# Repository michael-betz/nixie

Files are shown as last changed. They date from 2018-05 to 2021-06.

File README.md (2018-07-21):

# nixie
My exercise in OpenScad.
a HP 5245L frequency counter had to die for this ...

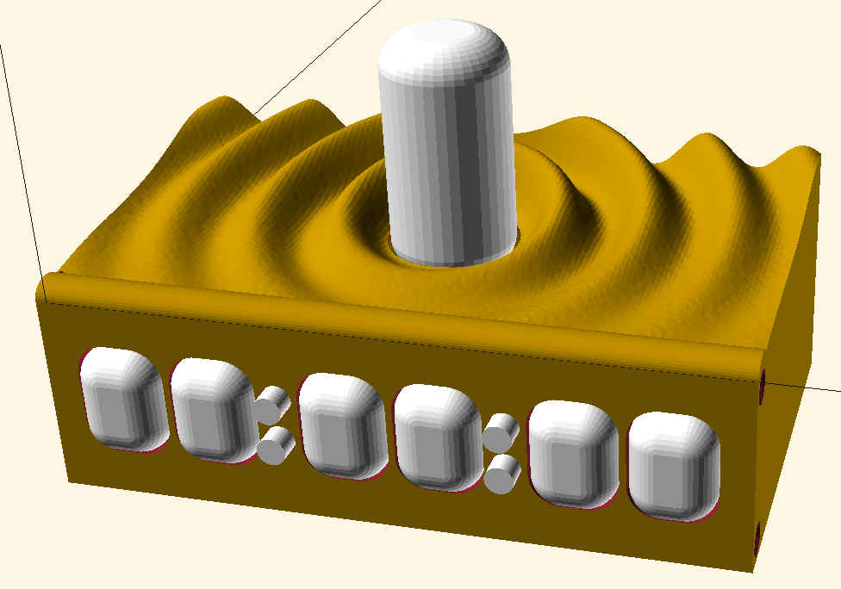
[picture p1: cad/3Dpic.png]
Nixie render

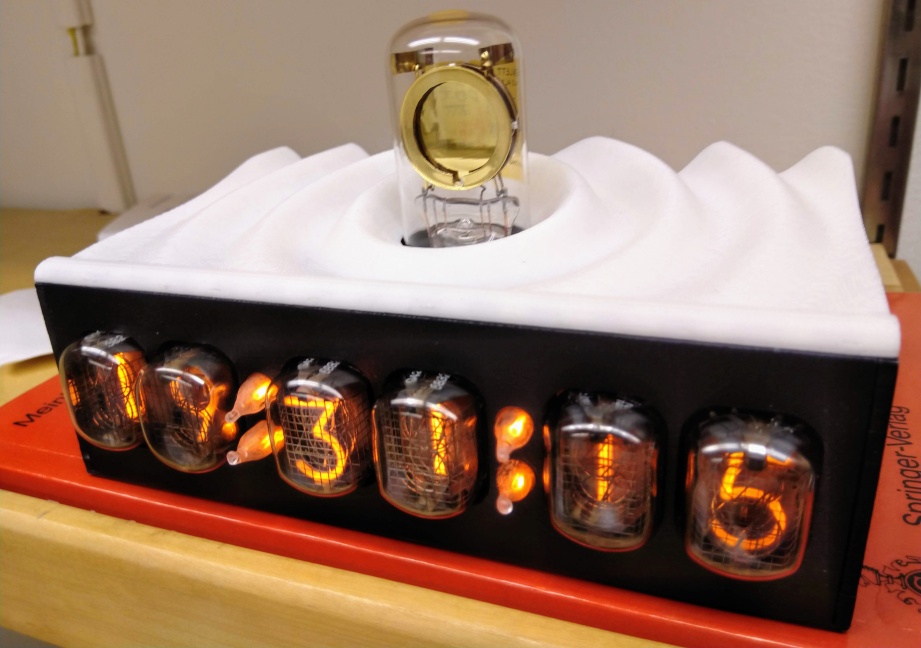
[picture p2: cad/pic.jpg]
Nixie photo


# Lessons learned the hard way
Murphy was strong on this one ...

  * Nixie pins are fragile and don't like too tight sockets. RIP 2 tubes ...
  * The HV5530 in a PQFP package has a different pinout than the one in a PLCC package. Fixed it with tons of botch wire :weary:
  * Didn't notice that the nixie tube datasheet shows the pinout from the bottom :unamused:. Fixed it with a lot more botch wire
  * Feel free to re-do the layout in kicad ...
  * Magnet wire insulation didn't hold up to 180 V. Killed 2 x ESP32 that way. Fixed it with conformal coating
  * Didn't keep conformal coating away from push buttons, it disabled them
  * Hole pattern between PCB and 3D print was off by ~ 3 mm due to a typo in the 3D model. Fixed it by bending the 3D printed part with a hot air gun
  * Had to cut some of the 3D printed stand-offs and the ESP32 PCB antenna to make it all fit

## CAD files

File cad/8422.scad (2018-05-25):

module pin() {
  translate([11.1/2, 0,        0]) cylinder(h=6, r=0.5);
  translate([11.1/2, 4.3,      0]) cylinder(h=6, r=0.5);
  translate([0,      17.1/2,   0]) cylinder(h=6, r=0.5);
  translate([sin(26)*17.1/2, cos(26)*17.1/2, 0]) cylinder(h=6, r=0.5);
}

module nixie8422(){
  smoothRad = 7;
  union(){
    minkowski(){
      cube(size=[18.85-smoothRad*2, 25.1-smoothRad*2, 20-smoothRad*2], center=true);
      sphere(r=smoothRad);
    }
    translate([0,0,-15]) union(){
      pin();
      mirror([0,1,0]) pin();
      mirror([1,0,0]) pin();
      mirror([0,1,0]) mirror([1,0,0]) pin();
    }
  }
}

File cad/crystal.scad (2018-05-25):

module crystal() {
  smoothRad = 8;
  minkowski(){
    cylinder(h=55.8-smoothRad*2, r=28.5/2-smoothRad, center=true);
    sphere(r=smoothRad);
  }
}

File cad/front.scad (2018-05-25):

// the complete frontpanel
module frontPanel(){
  difference(){
    translate([150/2,fpThickness/2,-45/2]) rotate([90,0,0]){
      difference(){
        cube(size=[150,45,fpThickness], center=true);
        nixies(1.06);
      }
      // PCB standoffs
      translate([0, 0, -pcbDist+0.5]) standOffSquare(138,33,2.7,pcbDist);
      // Teeth at the top
      translate([-150/2,45/2,2]) teeth(teethShrink, 140);
    }
    // bumper slots
    translate([0,21,0]) rotate([90,0,0]) bumpers(2.8, 20);
    // screw holes on the sides
    translate([ -0.1,fpThickness/2,   -4]) rotate([0,90,0]) cylinder(h=14, r=3.5/2);
    translate([ -0.1,fpThickness/2,-45+4]) rotate([0,90,0]) cylinder(h=14, r=3.5/2);
    translate([136.1,fpThickness/2,   -4]) rotate([0,90,0]) cylinder(h=14, r=3.5/2);
    translate([136.1,fpThickness/2,-45+4]) rotate([0,90,0]) cylinder(h=14, r=3.5/2);
  }
}

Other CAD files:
cad/helpers.scad
cad/lower.scad
cad/main.scad
cad/top.scad

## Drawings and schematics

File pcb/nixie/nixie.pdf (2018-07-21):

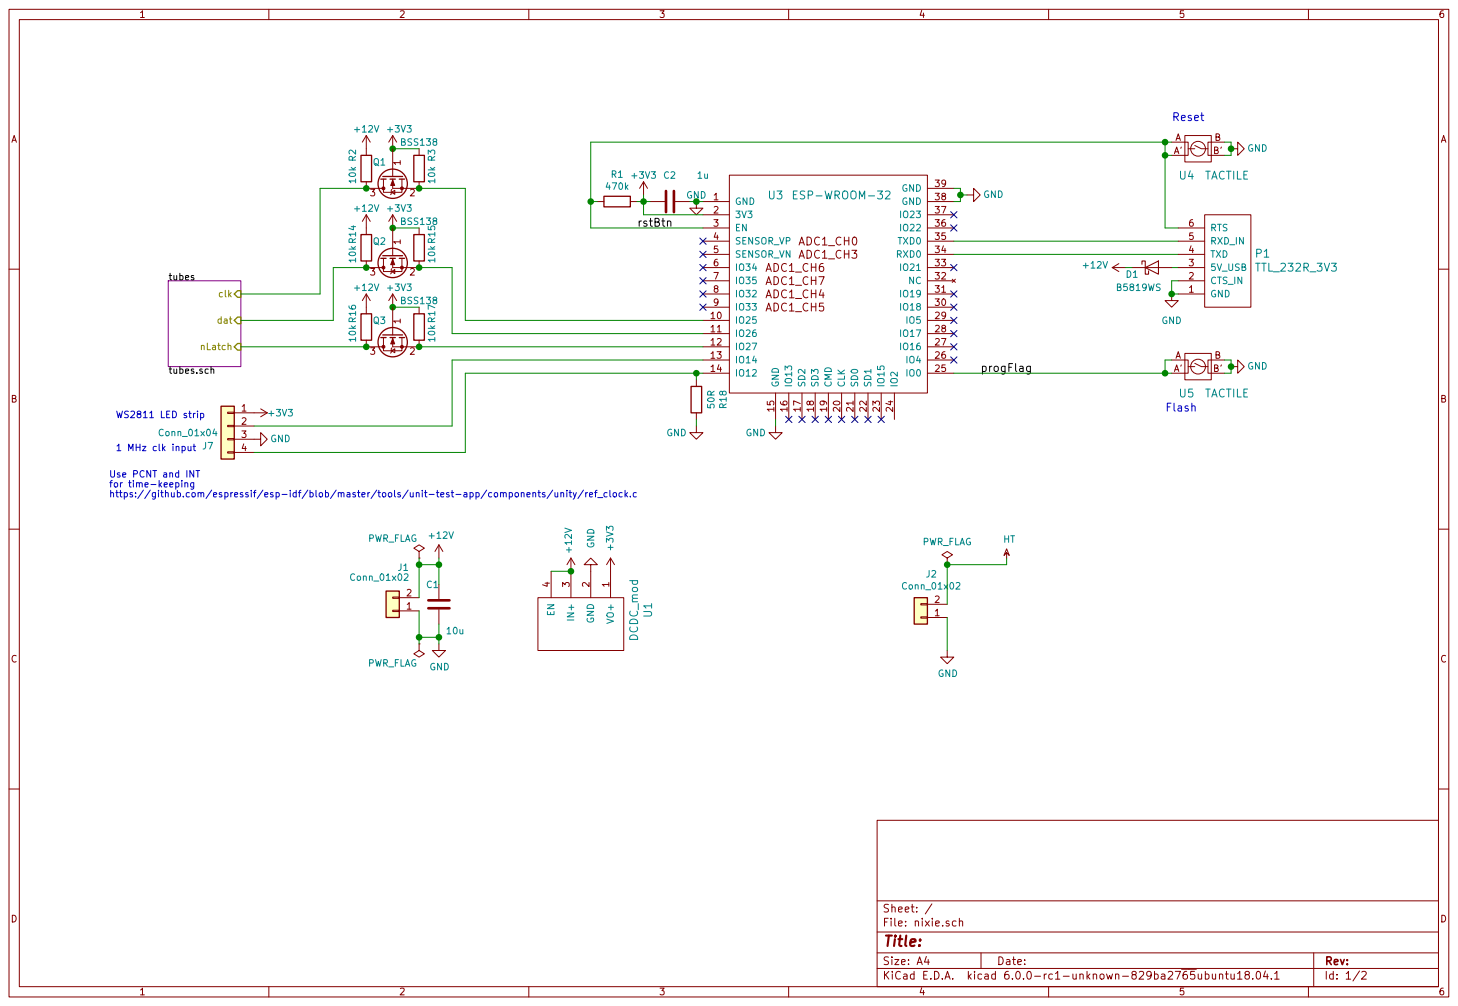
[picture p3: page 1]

1 MHz clk input Use PCNT and INT

Id: 1/2 Title: File: nixie.sch Sheet: /

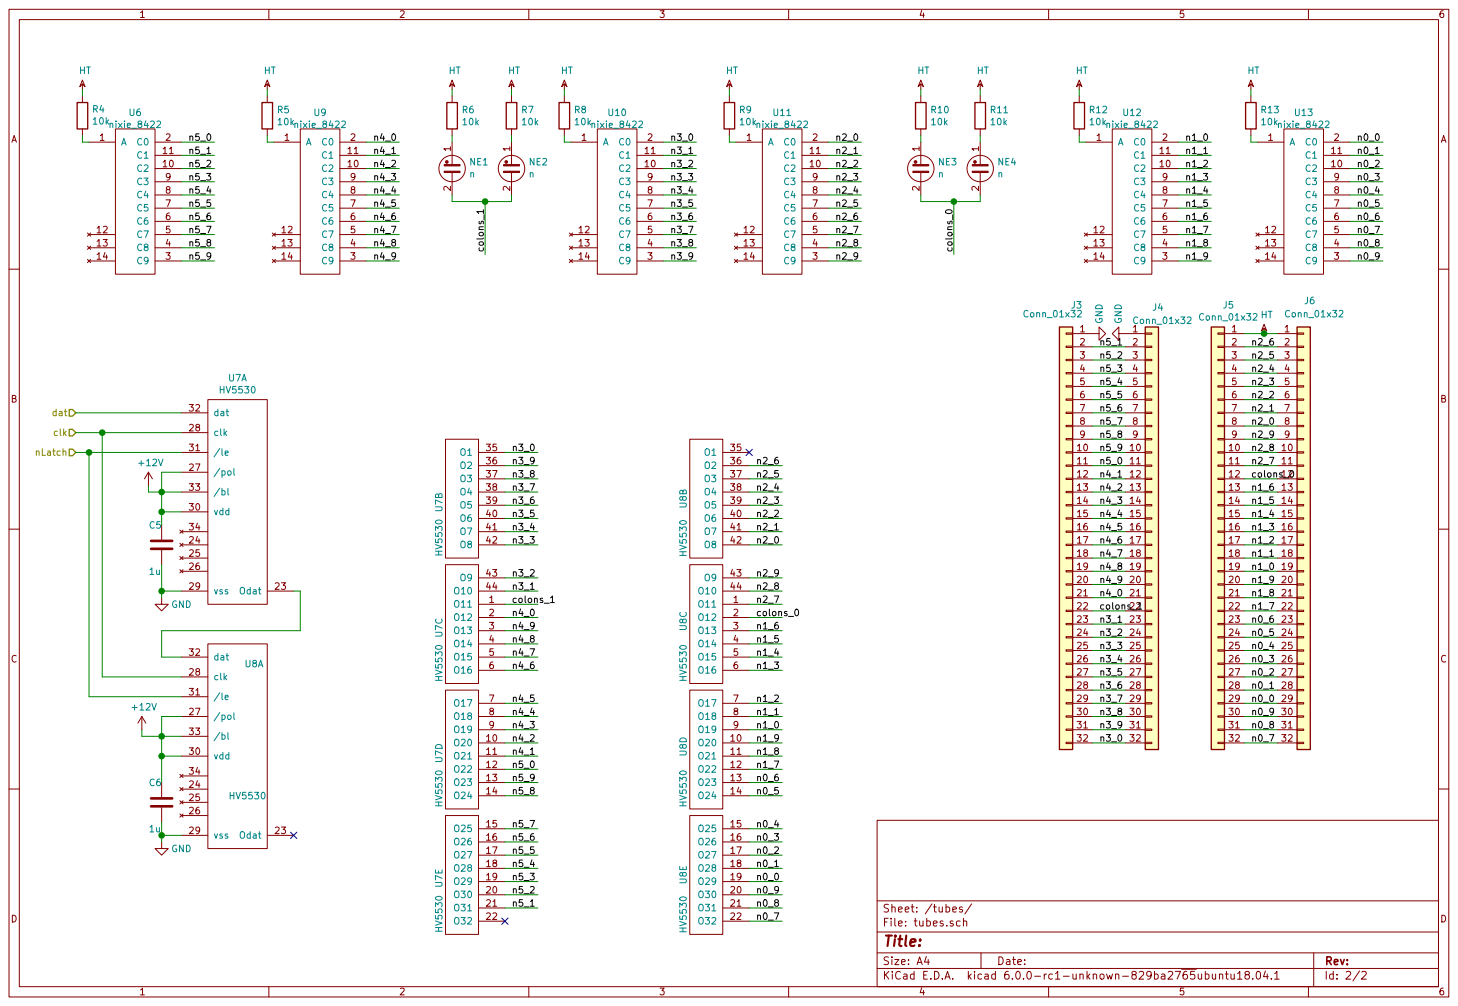
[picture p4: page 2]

Id: 2/2 Title: File: tubes.sch Sheet: /tubes/

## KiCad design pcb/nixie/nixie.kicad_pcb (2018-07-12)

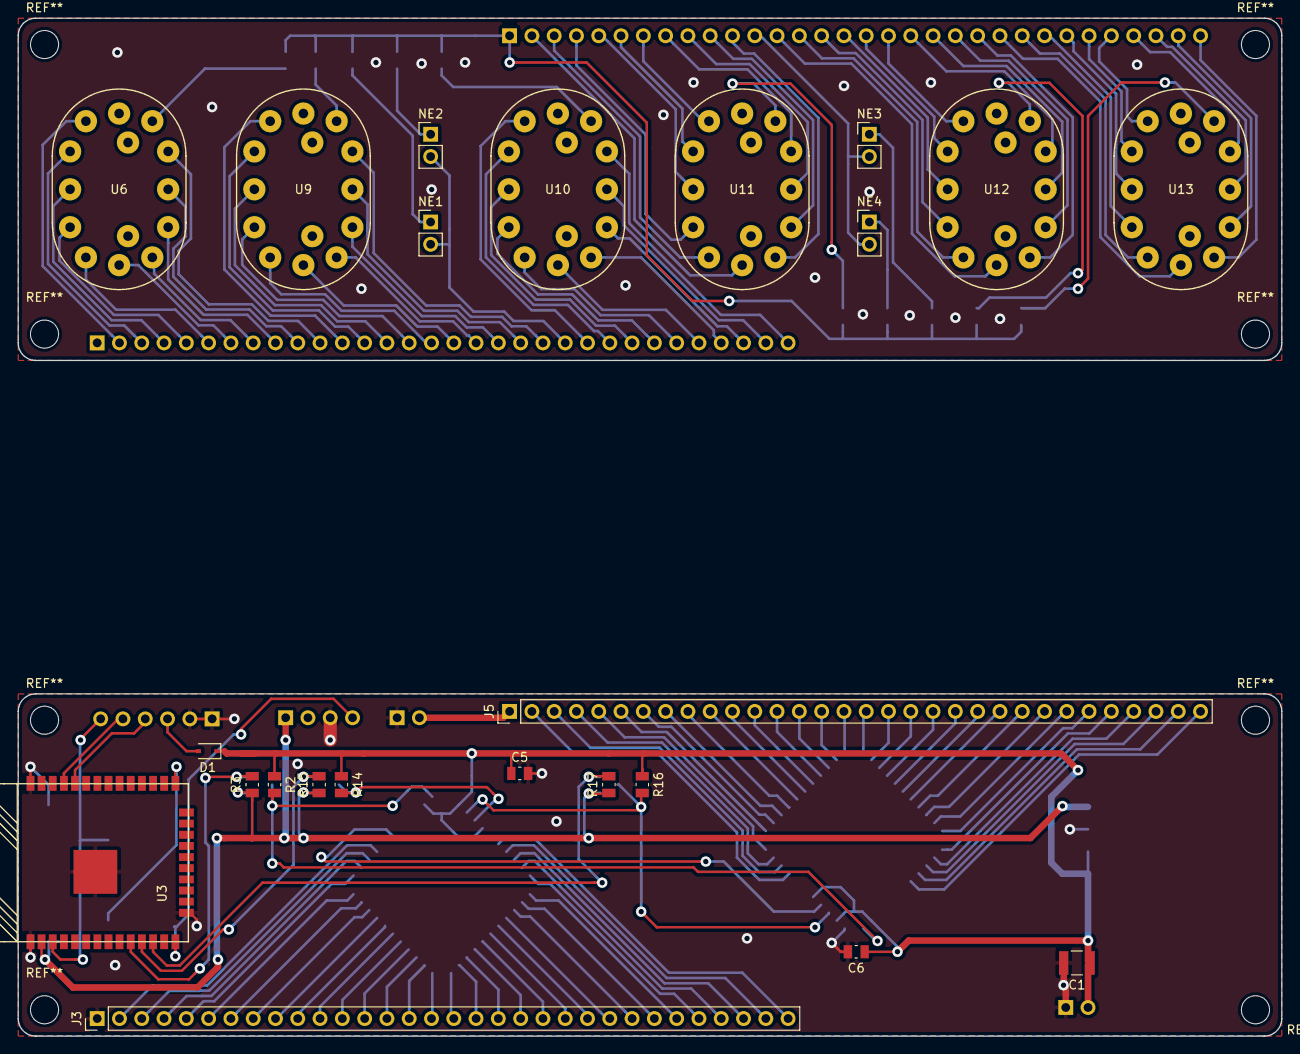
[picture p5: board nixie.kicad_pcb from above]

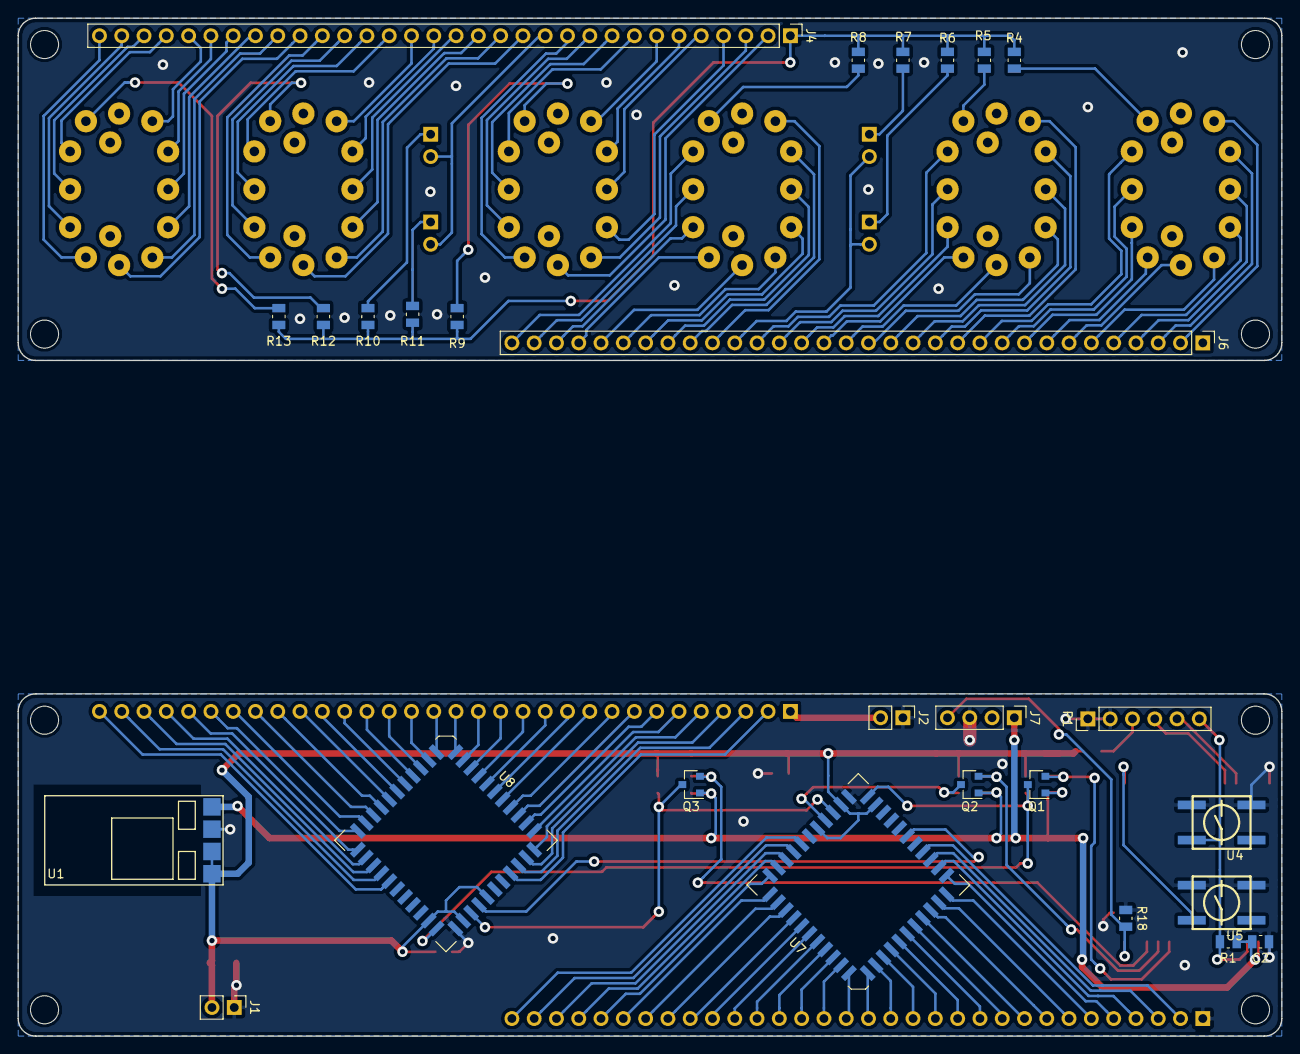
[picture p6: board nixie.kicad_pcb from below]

Board: 2 copper layers, 144.0 x 116.0 mm, 50 parts (27 on the bottom side), 90 nets.

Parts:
C1: 10u; C_1210_3225Metric
C2, C5, C6: 1u; C_0805_2012Metric
D1: B5819WS; D_SOD-323
J1, J2: Conn_01x02; PinHeader_1x02_P2.54mm_Vertical
J3, J4, J5, J6: Conn_01x32; PinHeader_1x32_P2.54mm_Vertical
J7: Conn_01x04; PinHeader_1x04_P2.54mm_Vertical
NE1, NE2, NE3, NE4: n; PinHeader_1x02_P2.54mm_Vertical
P1: TTL_232R_3V3; PinHeader_1x06_P2.54mm_Vertical
Q1, Q2, Q3: BSS138; SOT-23
R1: 470k; R_0805_2012Metric
R2, R3, R4, R5, R6, R7, R8, R9, R10, R11, R12, R13, R14, R15, R16, R17: 10k; R_0805_2012Metric
R18: 50R; R_0805_2012Metric
U1: DCDC_mod; ebay_dcdc
U3: ESP-WROOM-32
U4, U5: TACTILE; EVQQ2
U6, U9, U10, U11, U12, U13: nixie_8422
U7, U8: HV5530; PLCC-44

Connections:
+3V3: C2.2, J7.1, Q1.1, Q2.1, Q3.1, R1.1, R3.1, R15.1, R17.1, U1.1, U3.2
+12V: C1.1, C5.1, C6.1, D1.1, J1.2, R2.1, R14.1, R16.1, U1.3, U1.4, U7.27, U7.30, U7.33, U8.27, U8.30, U8.33
/progFlag: U3.25, U5.A, U5.A'
/rstBtn: P1.6, R1.2, U3.3, U4.A, U4.A'
/tubes/clk: Q1.3, R2.2, U7.28, U8.28
/tubes/colons_0: J5.12, J6.12, NE3.2, NE4.2, U8.2
/tubes/colons_1: J3.22, J4.22, NE1.2, NE2.2, U7.1
/tubes/dat: Q2.3, R14.2, U7.32
/tubes/n0_0: J5.29, J6.29, U8.19, U13.2
/tubes/n0_1: J5.28, J6.28, U8.18, U13.11
/tubes/n0_2: J5.27, J6.27, U8.17, U13.10
/tubes/n0_3: J5.26, J6.26, U8.16, U13.9
/tubes/n0_4: J5.25, J6.25, U8.15, U13.8
/tubes/n0_5: J5.24, J6.24, U8.14, U13.7
/tubes/n0_6: J5.23, J6.23, U8.13, U13.6
/tubes/n0_7: J5.32, J6.32, U8.22, U13.5
/tubes/n0_8: J5.31, J6.31, U8.21, U13.4
/tubes/n0_9: J5.30, J6.30, U8.20, U13.3
/tubes/n1_0: J5.19, J6.19, U8.9, U12.2
/tubes/n1_1: J5.18, J6.18, U8.8, U12.11
/tubes/n1_2: J5.17, J6.17, U8.7, U12.10
/tubes/n1_3: J5.16, J6.16, U8.6, U12.9
/tubes/n1_4: J5.15, J6.15, U8.5, U12.8
/tubes/n1_5: J5.14, J6.14, U8.4, U12.7
/tubes/n1_6: J5.13, J6.13, U8.3, U12.6
/tubes/n1_7: J5.22, J6.22, U8.12, U12.5
/tubes/n1_8: J5.21, J6.21, U8.11, U12.4
/tubes/n1_9: J5.20, J6.20, U8.10, U12.3
/tubes/n2_0: J5.8, J6.8, U8.42, U11.2
/tubes/n2_1: J5.7, J6.7, U8.41, U11.11
/tubes/n2_2: J5.6, J6.6, U8.40, U11.10
/tubes/n2_3: J5.5, J6.5, U8.39, U11.9
/tubes/n2_4: J5.4, J6.4, U8.38, U11.8
/tubes/n2_5: J5.3, J6.3, U8.37, U11.7
/tubes/n2_6: J5.2, J6.2, U8.36, U11.6
/tubes/n2_7: J5.11, J6.11, U8.1, U11.5
/tubes/n2_8: J5.10, J6.10, U8.44, U11.4
/tubes/n2_9: J5.9, J6.9, U8.43, U11.3
/tubes/n3_0: J3.32, J4.32, U7.35, U10.2
/tubes/n3_1: J3.23, J4.23, U7.44, U10.11
/tubes/n3_2: J3.24, J4.24, U7.43, U10.10
/tubes/n3_3: J3.25, J4.25, U7.42, U10.9
/tubes/n3_4: J3.26, J4.26, U7.41, U10.8
/tubes/n3_5: J3.27, J4.27, U7.40, U10.7
/tubes/n3_6: J3.28, J4.28, U7.39, U10.6
/tubes/n3_7: J3.29, J4.29, U7.38, U10.5
/tubes/n3_8: J3.30, J4.30, U7.37, U10.4
/tubes/n3_9: J3.31, J4.31, U7.36, U10.3
/tubes/n4_0: J3.21, J4.21, U7.2, U9.2
/tubes/n4_1: J3.12, J4.12, U7.11, U9.11
/tubes/n4_2: J3.13, J4.13, U7.10, U9.10
/tubes/n4_3: J3.14, J4.14, U7.9, U9.9
/tubes/n4_4: J3.15, J4.15, U7.8, U9.8
/tubes/n4_5: J3.16, J4.16, U7.7, U9.7
/tubes/n4_6: J3.17, J4.17, U7.6, U9.6
/tubes/n4_7: J3.18, J4.18, U7.5, U9.5
/tubes/n4_8: J3.19, J4.19, U7.4, U9.4
/tubes/n4_9: J3.20, J4.20, U7.3, U9.3
/tubes/n5_0: J3.11, J4.11, U6.2, U7.12
/tubes/n5_1: J3.2, J4.2, U6.11, U7.21
/tubes/n5_2: J3.3, J4.3, U6.10, U7.20
/tubes/n5_3: J3.4, J4.4, U6.9, U7.19
/tubes/n5_4: J3.5, J4.5, U6.8, U7.18
/tubes/n5_5: J3.6, J4.6, U6.7, U7.17
/tubes/n5_6: J3.7, J4.7, U6.6, U7.16
/tubes/n5_7: J3.8, J4.8, U6.5, U7.15
/tubes/n5_8: J3.9, J4.9, U6.4, U7.14
/tubes/n5_9: J3.10, J4.10, U6.3, U7.13
/tubes/nLatch: Q3.3, R16.2, U7.31, U8.31
GND: C1.2, C2.1, C5.2, C6.2, J1.1, J2.1, J3.1, J4.1, J7.3, P1.1, P1.2, R18.1, U1.2, U3.1, U3.15, U3.38, U3.39, U4.B, U4.B', U5.B, U5.B', U7.29, U8.29
HT: J2.2, J5.1, J6.1, R4.2, R5.1, R6.1, R7.1, R8.1, R9.1, R10.1, R11.1, R12.1, R13.1
unnamed: D1.2, P1.3
unnamed: J7.2, U3.13
unnamed: J7.4, R18.2, U3.14
unnamed: NE1.1, R6.2
unnamed: NE2.1, R7.2
unnamed: NE3.1, R10.2
unnamed: NE4.1, R11.2
unnamed: P1.4, U3.34
unnamed: P1.5, U3.35
unnamed: Q1.2, R3.2, U3.10
unnamed: Q2.2, R15.2, U3.11
unnamed: Q3.2, R17.2, U3.12
unnamed: R4.1, U6.1
unnamed: R5.2, U9.1
unnamed: R8.2, U10.1
unnamed: R9.2, U11.1
unnamed: R12.2, U12.1
unnamed: R13.2, U13.1
unnamed: U7.23, U8.32

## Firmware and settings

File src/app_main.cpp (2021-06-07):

#include <stdio.h>
#include <string.h>
#include <stdlib.h>
#include <math.h>
#include <time.h>
#include "driver/gpio.h"
#include "ArduinoOTA.h"
#include "app_main.h"
#include "rom/ets_sys.h"
#include "Arduino.h"
#include "WiFi.h"
#include "SPIFFS.h"
#include "freertos/FreeRTOS.h"
#include "freertos/task.h"
#include "rom/rtc.h"
#include "esp_comms.h"
#include "web_console.h"
#include "json_settings.h"
#include "esp_heap_caps.h"

// Web socket RX data received callback
static void on_ws_data(
    AsyncWebSocket * server,
    AsyncWebSocketClient * client,
    AwsEventType type,
    void * arg,
    uint8_t *data,
    size_t len
) {
    switch (data[0]) {
        case 'a':
            wsDumpRtc(client);  // read rolling log buffer in RTC memory
            break;

        case 'b':
            settings_ws_handler(client, data, len);  // read / write settings.json
            break;

        case 'r':
            ESP.restart();
            break;

        case 'h':
            client->printf(
                "h{\"heap\": %d, \"min_heap\": %d}",
                ESP.getFreeHeap(), ESP.getMinFreeHeap()
            );
            break;
    }
}

void initGpio(void)
{
    gpio_config_t io_conf;
    io_conf.intr_type = GPIO_INTR_DISABLE;
    io_conf.mode = GPIO_MODE_OUTPUT;
    io_conf.pin_bit_mask = (1<<PIN_CLK) | (1<<PIN_DAT) | (1<<PIN_N_LATCH) | (1<<PIN_LED_DAT);
    io_conf.pull_down_en = GPIO_PULLDOWN_DISABLE;
    io_conf.pull_up_en = GPIO_PULLUP_DISABLE;
    gpio_config(&io_conf);
}

static void shiftOut( uint8_t *data, unsigned len )
{
    while (len--) {
        uint8_t tmp = *data++;
        for (unsigned bit = 0; bit <= 7; bit++){
            gpio_set_level(PIN_CLK, 1);
            gpio_set_level(PIN_DAT, !(tmp & 0x80));
            ets_delay_us(SHIFT_DEL);
            tmp <<= 1;
            gpio_set_level(PIN_CLK, 0);
            ets_delay_us(SHIFT_DEL);
        }
    }
    gpio_set_level(PIN_N_LATCH, 1);
    ets_delay_us(SHIFT_DEL);
    gpio_set_level(PIN_N_LATCH, 0);
}

// Mapping of output channels g_digitLookup[X][Y]
// X = nixie index (from right)
// Y = digit
uint8_t g_digitLookup[6][10] = {
//    0  1  2  3  4  5  6  7  8  9
    {25, 4, 5, 6, 7,28, 3,24,27,26},
    { 1,10,11,12,13,14, 9, 2,15, 0},
    {22,31,16,17,18,19,30,23,20,21},
    {63,50,51,52,53,54,49,48,61,62},
    {42,45,46,47,32,33,44,43,40,41},
    {36,39,60,58,57,56,38,37,34,35}
};

#define BIT_COLON1  8
#define BIT_COLON2 55

uint64_t getTimeVal( uint8_t *secs )
{
    uint64_t val = 0;
    time_t now=0;
    struct tm t = { 0 };
    time(&now);
    localtime_r(&now, &t);
    val |= (1LL) << (g_digitLookup[0][ t.tm_sec%10]);
    val |= (1LL) << (g_digitLookup[1][ t.tm_sec/10]);
    val |= (1LL) << (g_digitLookup[2][ t.tm_min%10]);
    val |= (1LL) << (g_digitLookup[3][ t.tm_min/10]);
    val |= (1LL) << (g_digitLookup[4][t.tm_hour%10]);
    val |= (1LL) << (g_digitLookup[5][t.tm_hour/10]);
    if( secs ) *secs = t.tm_sec;
    return val;
}

void setup()
{
    initGpio();
    uint64_t zeros=0;
    shiftOut((uint8_t*)(&zeros), 8);

    // report initial status
    log_w(
        "reset reason: %d, heap: %d, min_heap: %d",
        rtc_get_reset_reason(0),
        esp_get_free_heap_size(),
        esp_get_minimum_free_heap_size()
    );

    // forwards each serial character to web-console
    web_console_init();
    log_w(
        "after web_console, heap: %d, min_heap: %d",
        esp_get_free_heap_size(),
        esp_get_minimum_free_heap_size()
    );

    SPIFFS.begin(true, "/spiffs", 5);
    log_w(
        "after SPIFFS, heap: %d, min_heap: %d",
        esp_get_free_heap_size(),
        esp_get_minimum_free_heap_size()
    );

    // When settings.json cannot be opened, it will copy the default_settings over
    set_settings_file("/spiffs/settings.json", "/spiffs/default_settings.json");
    log_w(
        "after settings, heap: %d, min_heap: %d",
        esp_get_free_heap_size(),
        esp_get_minimum_free_heap_size()
    );

    init_comms(SPIFFS, "/", on_ws_data);
    log_w(
        "after init_comms, heap: %d, min_heap: %d",
        esp_get_free_heap_size(),
        esp_get_minimum_free_heap_size()
    );

    // This is how to access a string item from settings.json
    log_d(
        "settings[hostname] = %s",
        jGetS(getSettings(), "hostname", "fallback_value")
    );
}

void loop() {
    uint64_t val1=0, val2=0;
    uint8_t sec=0, osec=0;
    // for( unsigned i=0; i<6; i++ ){
    //     for( unsigned d=0; d<10; d++ ){
    //         ESP_LOGI(T, "[%d,%d]", i, d);
    //         val = (1LL)<<(g_digitLookup[i][d]);
    //         shiftOut((uint8_t*)(&val), 8);
    //         vTaskDelay(100 / portTICK_RATE_MS);
    //     }
    // }
    val1 = getTimeVal(&sec);
    val2 = val1 | (1LL) << (BIT_COLON1) | (1LL) << (BIT_COLON2);
    if(sec != osec){
        osec = sec;
        // shiftOut((uint8_t*)(&val2), 8);
        vTaskDelay(15 / portTICK_RATE_MS);
    }
    shiftOut((uint8_t*)(&val1), 8);

    g_ws.cleanupClients();
    ArduinoOTA.handle();
    vTaskDelay(100 / portTICK_RATE_MS);
}

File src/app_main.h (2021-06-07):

#ifndef APP_MAIN_H
#define APP_MAIN_H

// Random number within the range [a,b]
#define RAND_AB(a,b) (rand()%(b+1-a)+a)

#define SHIFT_DEL   100     // Bit banging delay [us]

#define PIN_CLK     GPIO_NUM_13
#define PIN_DAT     GPIO_NUM_26
#define PIN_N_LATCH GPIO_NUM_27
#define PIN_LED_DAT GPIO_NUM_14
#define PIN_1MHZ_IN GPIO_NUM_12

#endif

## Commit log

2018-04-16 The vision
    [8422.scad, crystal.scad, frontpanel.scad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]
2018-04-20 case work
    [frontpanel.scad]
2018-05-07 Not sure where im going here
    [nixie.kicad_pcb, tubes.sch]
2018-05-14 PCB work
    [main.scad, nixie.kicad_pcb, nixie.sch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]
2018-05-18 Added MCP1630 idea
    [boost.sch, nixie.sch, tubes.sch]
2018-05-20 rendered top
    [main.scad]
2018-05-20 larger lid
    [main.scad]
2018-05-21 done, done done done
    [main.scad, nixie.kicad_pcb, nixie.sch]
2018-05-22 added finished frontpanel
    [frontpanel.stl, main.scad]
2018-05-23 Finished lower part
    [lower.stl, main.scad, nixie.kicad_pcb]
2018-05-24 Decided for 12V input voltage
    [nixie.kicad_pcb, nixie.sch, tubes.sch]
2018-05-24 Major cleanup.
    Split 3 parts into 3 modules for separate printing.
    Fix Mounting holes for PCB behind frontpanel,
    which were off by 1 mm each.
    Increase Z-depth of teeth slots (x1.5).
    Remove outdated pictures and stl files
    [8422.scad, crystal.scad, front.scad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]
2018-05-25 Technically done
    [nixie.kicad_pcb]
2018-05-30 Minor imprpvements
    [nixie.kicad_pcb]
2018-07-12 Wrong pinout on HV5530 :(
    [nixie.kicad_pcb]
2018-07-21 added 3D pic
    [main.scad]
2021-06-07 make it a platformio project
    * use esp-comms to bring up wifi, manage settings in a .json and run the web-interface
    [partitions.csv]
